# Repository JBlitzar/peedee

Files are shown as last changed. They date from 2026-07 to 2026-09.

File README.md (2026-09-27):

# peedee

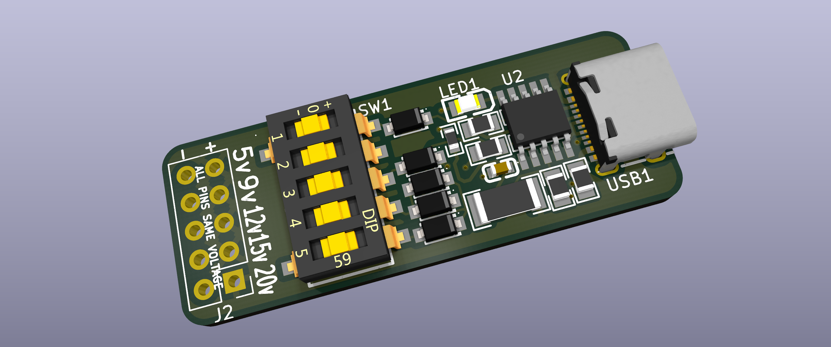
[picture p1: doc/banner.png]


USB-C power delivery board

## What this project is and why I made it

It's a USB-C power delivery board. It uses just a bare CH224k with no MCU or other ICs, but it also offers convenience through its user interface,  which allows users to select voltage levels without needing to look at a complex silkscreen lookup table. Instead, I used a diode-matrix ROM to convert one-hot encoded voltage selections into the proper signals for the three binary configuration lines. The schematic is deceptively simple-- I had to translate the datasheet and invent the diode ROM. One unexpected tricky part of this project was *resistor sorting*. This is because peedee, as per the reference schematic, **doesn't use an LDO**. Instead, it uses a 1k resistor and a decoupling cap 💀. Uniquely though, PD can draw medium-high voltages and currents, so the resistor has to be well-rated. Not only that, but it needs to be SMD, a relatively small footprint, and in stock on LCSC. This constrains my resistor choices from potentially tens of thousands of listings to just a few. Anyways, that was interesting.

I also like how it ended up in such a small footprint-- about the size of the top half of your pinky finger. Part density is especially high though because most of the footprints are bigger than 0402. I made it long and skinny, and in this way, it seems like a natural extension of the long and skinny USB cable that powers it.

## PCB Images

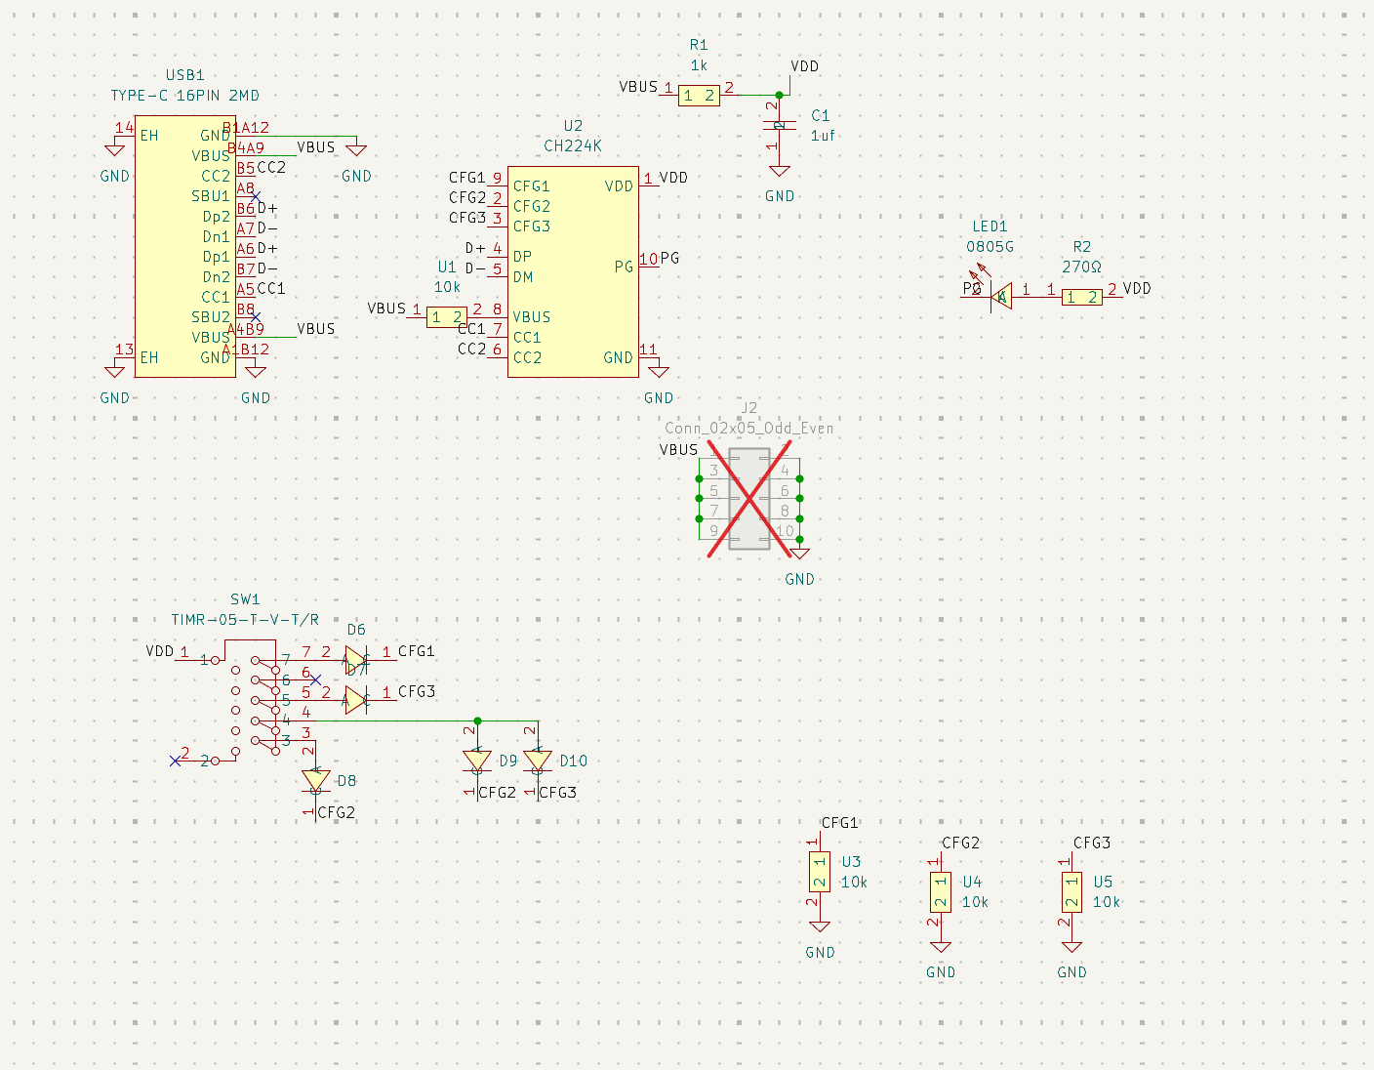
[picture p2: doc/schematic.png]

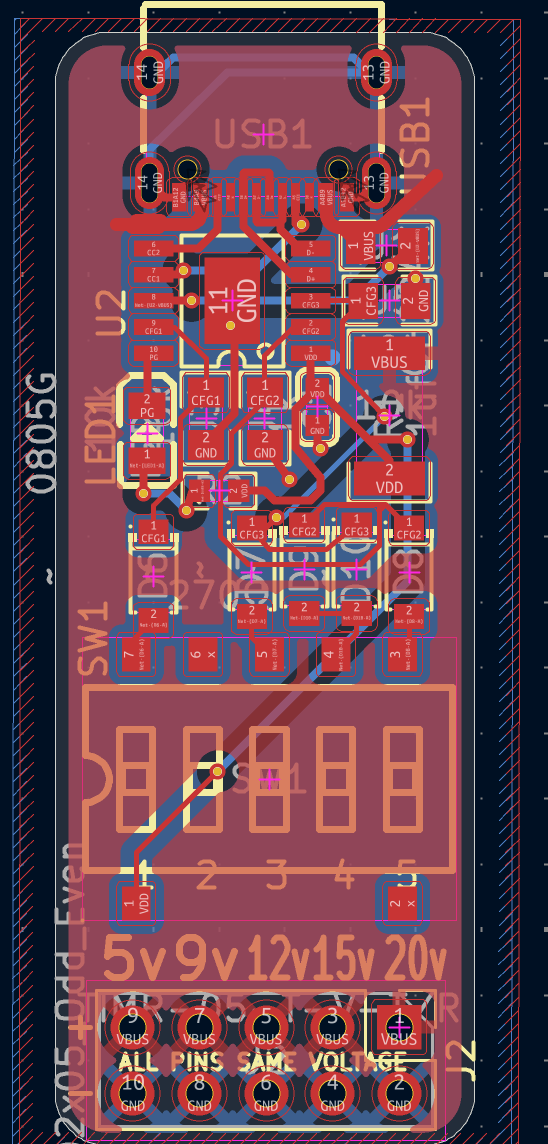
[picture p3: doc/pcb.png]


## Overall BOM

|Item |Cost |
|---|-----|
|PCB |2 |
|PCBA |32.56|
|Shipping|3.3  |
|Taxes |3 |
|Total |40.86|

# Fabrication BOM

Looking for other fabrication outputs? This BOM in CSV form, plus the pnp files and gerbers, are in [PCB/peedee/production_real](PCB/peedee/production_real)

|Designator |Footprint |Quantity|Value |LCSC Part #|
|---|---|---|---|---|
|C1 |C0603 |1 |1uf |C15849 |
|D10, D6, D7, D8, D9|SOD-123_L2.8-W1.8-LS3.7-RD-1 |5 |~ |C81598 |
|LED1 |LED0805-R-RD |1 |0805G |C2297 |
|R1 |R2010 |1 |1k |C2974087 |
|R2 |R0603 |1 |270Ω |C22966 |
|SW1 |SW-SMD_TIMR-05-T-V-T-R |1 |TIMR-05-T-V-T/R |C388479 |
|U1, U3, U4, U5 |R0805 |4 |10k |C17414 |
|U2 |ESSOP-10_L4.9-W3.9-P1.0-LS6.0-TL-EP|1 |CH224K |C970725 |
|USB1 |USB-C-SMD_TYPE-C-16PIN-2MD-073 |1 |TYPE-C 16PIN 2MD|C2765186 |

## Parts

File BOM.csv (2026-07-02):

Item | Cost
PCB | 2
PCBA | 32.56
Shipping | 3.3
Taxes | 3
Total | 40.86

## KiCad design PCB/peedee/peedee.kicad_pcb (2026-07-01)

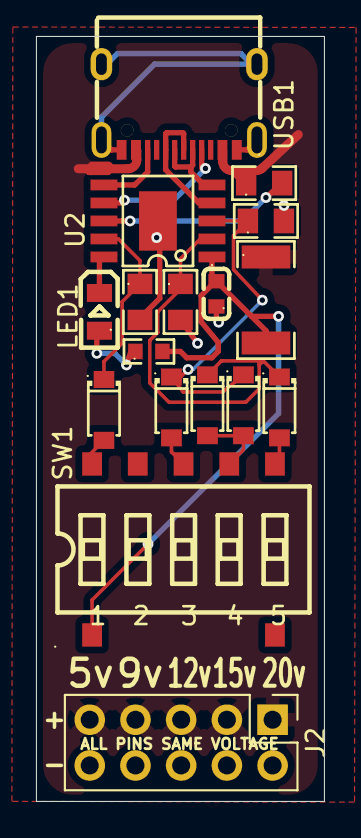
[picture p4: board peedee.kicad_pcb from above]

Board: 2 copper layers, 16.0 x 42.5 mm, 17 parts (0 on the bottom side), 17 nets.

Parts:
C1: 1uf; C0603
D6, D7, D8, D9, D10: SOD-123_L2.8-W1.8-LS3.7-RD-1
J2: Conn_02x05_Odd_Even; PinHeader_2x05_P2.54mm_Vertical
LED1: 0805G; LED0805-R-RD
R1: 1k; R2010
R2: 270Ω; R0603
SW1: TIMR-05-T-V-T/R; SW-SMD_TIMR-05-T-V-T-R
U1, U3, U4, U5: 10k; R0805
U2: CH224K; ESSOP-10_L4.9-W3.9-P1.0-LS6.0-TL-EP
USB1: TYPE-C 16PIN 2MD; USB-C-SMD_TYPE-C-16PIN-2MD-073

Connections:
/CC1: U2.7 (CC1), USB1.A5 (CC1)
/CC2: U2.6 (CC2), USB1.B5 (CC2)
/CFG1: D6.1 (C), U2.9 (CFG1), U3.1
/CFG2: D8.1 (C), D9.1 (C), U2.2 (CFG2), U4.1
/CFG3: D7.1 (C), D10.1 (C), U2.3 (CFG3), U5.1
/D+: U2.4 (DP), USB1.A6 (Dp1), USB1.B6 (Dp2)
/D-: U2.5 (DM), USB1.A7 (Dn1), USB1.B7 (Dn2)
/PG: LED1.2 (K), U2.10 (PG)
/VBUS: J2.1, J2.3, J2.5, J2.7, J2.9, R1.1, U1.1, USB1.A4B9 (VBUS), USB1.B4A9 (VBUS)
/VDD: C1.2, R1.2, R2.2, SW1.1, U2.1 (VDD)
GND: C1.1, J2.2, J2.4, J2.6, J2.8, J2.10, U2.11 (GND), U3.2, U4.2, U5.2, USB1.13 (EH), USB1.14 (EH), USB1.A1B12 (GND), USB1.B1A12 (GND)
unnamed: D6.2 (A), SW1.7
unnamed: D7.2 (A), SW1.5
unnamed: D8.2 (A), SW1.3
unnamed: D9.2 (A), D10.2 (A), SW1.4
unnamed: LED1.1 (A), R2.1
unnamed: U1.2, U2.8 (VBUS)

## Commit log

2026-07-01 lwk the pcb
    [peedee.kicad_pcb, peedee.kicad_sch]
2026-07-02 all the docs
    [BOM.csv, peedee.kicad_sch, peedee_1_bom.csv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]
